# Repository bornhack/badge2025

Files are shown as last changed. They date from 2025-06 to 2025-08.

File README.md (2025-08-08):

# BornHack 2025 Circle Badge with LoRa

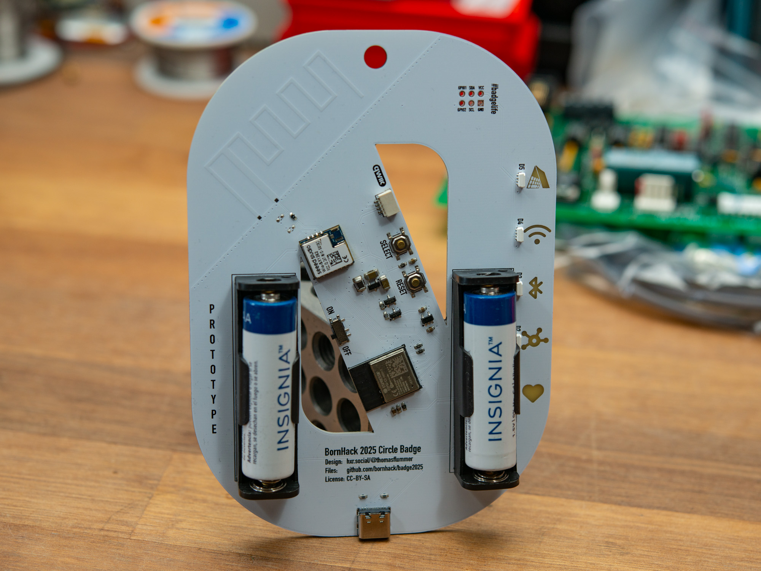
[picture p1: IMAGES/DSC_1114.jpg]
BornHack 2025 Circle Badge with LoRa (prototype)


This badge focuses on LoRa and wireless communication in general, as there are also WiFi and Bluetooth Low Energy included in the ESP32-C3 module.

It's a relatively bare bone design, with pretty much just the minimum elements to run a Meshtastic node or similar device.

Even though there is an antenna on the PCB for LoRa (868MHz) it's unfortunately not connected as the [LoRa module](https://www.seeedstudio.com/Wio-SX1262-Wireless-Module-p-5981.html) is the variant that has a connector (uf.L/IPEX), so an [external antenna](https://www.molex.com/en-us/products/part-detail/2111400100) is provided in the kit, that is designed to match with the connector on the module. The external antenna has selfadhesive backing, but don't mount it to the PCB, as most of the PCB is covered with copper, which will heavily decrese the performance, so if you want to stick it to something, better use a plastic case or similar.

The badge comes preinstalled with [Meshtastic](https://meshtastic.org/) firmware, that you can hook up to and configure using the Mestastic app on your phone (Android or iOS). The two apps are slightly different, but does have more or less the same overall features.

If you want to use Meshtastic for a longer period, it's recommended to power the badge via USB-C (simple  5V, eg. power bank or power adapter).

In addition to the LoRa module, there are 5 RGB LEDs on the side, a qwiic/StemmaQT connector and a footprint for a SAO v1.69bis connector for expansions, mostly for alternative firmwares.

## 3D Printable case

In the ```case``` folder is a desing, done in OpenSCAD, for a half or back case, that snaps on to the PCB and covers the back part with the battery holders, antenna and LEDs.

There are two versions, one fully closed, and one with a cutout for mounting it on a wall using a screw.

Both should print on most FDM printers without the need for support, with the back side facing down on the build plate.

## Projects running on the badge

Feel free to submit a PR adding on to this list with your project that runs on the badge.

- [Initial Meshtastic firmware](https://github.com/badgeteam/bornhack2025-meshtastic) ([Flasher tool](https://github.com/badgeteam/bornhack2025-flasher))
- _project name and link to more info_

## Designed in KiCad v9

To open the project, you will need to install a recent release version or one of the nightly builds, KiCad v8 or earlier won't open this design. The [schematic as a PDF](https://github.com/bornhack/badge2025/raw/main/schematics.pdf) is included for reference.

## License

The hardware design of the `main` branch of this repository is released under the following license:

* the "Creative Commons Attribution-ShareAlike 4.0 International License"
  (CC BY-SA 4.0) full text of this license is included in the LICENSE file
  and a copy can also be found at
  [http://creativecommons.org/licenses/by-sa/4.0/](http://creativecommons.org/licenses/by-sa/4.0/)

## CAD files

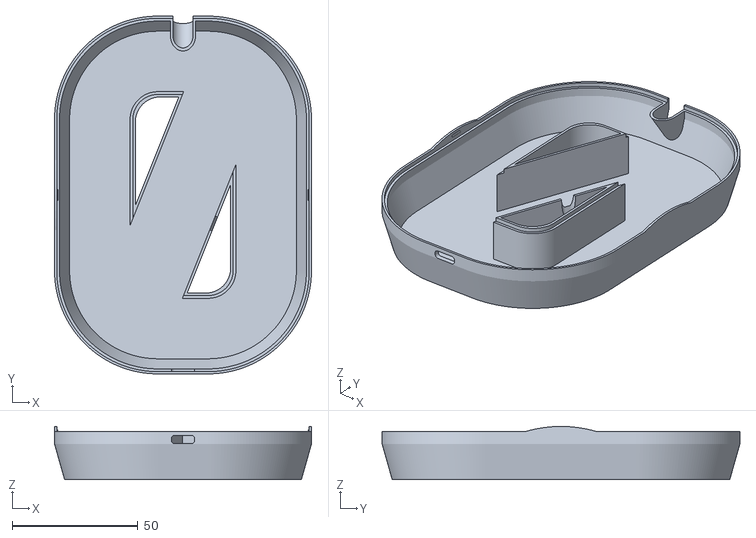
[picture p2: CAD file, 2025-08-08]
case/circle_badge_back_case.stl
102.0 x 142.0 x 21.1

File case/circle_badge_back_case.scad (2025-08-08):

/*
 * Case for BornHack 2025 badge
 *
 * Design: hxr.social/@thomasflummer
 *
 * License: CC-BY-SA
 *
 */

module half_rounded_cube(x, y, z, radius)
{
	hull()
	{
		for(xp = [-1, 1])
		{
			for(yp = [-1, 1])
			{
				for(zp = [-1, 1])
				{
					translate([xp*(x/2-radius), yp*(y/2-radius), zp*(z/2-0.1/2)])
						cylinder(r = radius, h = 0.1, center = true, $fn = 200);
				}
			}
		}
	}
}

module case()
{
	difference()
	{
		union()
		{
			hull()
			{
				translate([0, 0, -5/2+1.6])
					half_rounded_cube(100+2, 140+2, 5, 40+1);

				translate([0, 0, -16])
					half_rounded_cube(100-6, 140-6, 3, 40-3);
			}
			
			// extra sides for holding notches
			intersection()
			{
				translate([0, 0, 1.6])
					half_rounded_cube(100+2, 140+2, 10, 40+1);

				union()
				{
					for(xp = [-1, 1])
					{
						translate([xp*(100/2+0.1+1/2), 0, -100/2+1.6+2])
						rotate(90, [0, 1, 0])
							cylinder(d = 100, h = 1, center = true, $fn = 100);
					}
				}
			}
		}
		union()
		{
			// PCB cutout
			difference()
			{
				translate([0, 0, 1.6/2])
					half_rounded_cube(100+.2, 140+.2, 1.61, 40+0.1);

				difference()
				{
					translate([0, 0, 0])
						half_rounded_cube(40-.2, 80-.2, 40, 10-0.1);
						
					translate([0, 0, 0])
					rotate(-atan(20/50), [0, 0, 1])
						cube([29.8 + 0.2, 100, 40.1], center = true);
				}
			}

			// main opening
			difference()
			{
				hull()
				{
					translate([0, 0, -5/2+1.6])
						half_rounded_cube(100-2, 140-2, 5, 40-1);

					translate([0, 0, -16+1.5])
						half_rounded_cube(100-6-4, 140-6-4, 3, 40-3-2);
				}

				difference()
				{
					translate([0, 0, 0])
						half_rounded_cube(40+2, 80+2, 40, 10+1);
						
					translate([0, 0, 0])
					rotate(-atan(20/50), [0, 0, 1])
						cube([29.8+0.2, 100, 40.1], center = true);
				}
				
				// lanyard opening sides
				hull()
				{
					translate([0, 140/2, -5/2+1.6])
					rotate(35, [1, 0, 0])
						half_rounded_cube(10, 20, 30, 5);
					
				}
			}

			// lanyard cutout
			hull()
			{
				translate([0, 140/2, -5/2+1.6])
				rotate(35, [1, 0, 0])
					half_rounded_cube(8, 18, 30, 4);
				
			}

			// inner openings
			difference()
			{
				translate([0, 0, 0])
					half_rounded_cube(40-.2-2, 80-.2-2, 40, 10-0.1);
					
				translate([0, 0, 0])
				rotate(-atan(20/50), [0, 0, 1])
					cube([29.8 + 0.2 + 2, 100, 40.1], center = true);
			}
			
			// power switch
			translate([0, 0, 0])
			rotate(-atan(20/50), [0, 0, 1])
			translate([29.8/2+1.5, -6, 0])
			rotate(-15, [0, 1, 0])
				half_rounded_cube(4, 6, 12, 2);

			// USB-C cutout
			translate([0, -140/2, -3.2/2])
			rotate(90, [1, 0, 0])
				half_rounded_cube(9.2, 3.2, 20, 1.2);

			hull()
			{
				translate([0, -140/2+10/2, -3.2/2])
				rotate(90, [1, 0, 0])
					half_rounded_cube(9.2, 3.2, 10, 1.2);

				translate([0, -140/2+10/2, -3.2/2+3])
				rotate(90, [1, 0, 0])
					half_rounded_cube(9.2, 3.2, 10, 1.2);
			}

			// wall mounting hole
			translate([0, 140/2-20, -16])
				cylinder(d = 10, h = 10, center = true, $fn = 100);

			translate([0, 140/2-20, -16])
			hull()
			{
				cylinder(d = 4.5, h = 10, center = true, $fn = 100);

				translate([0, 8, 0])
					cylinder(d = 4.5, h = 10, center = true, $fn = 100);
			}
		}
	}
	
	// holding nothches
	union()
	{
		for(xp = [-1, 1])
		{
			translate([xp*(100/2+0.2), 0, 1.6+0.4])
			hull()
			{
				for(yp = [-1, 1])
				{
					translate([0, yp*2, 0])
						#sphere(d = 1, $fn = 50);
				}
			}
		}
	}

}

difference()
{
	union()
	{
		color("#ffafc7")
		case();

		if(true)
		{
			//color("#ffffff")
			translate([-100/2, 140/2, 0])
				%import("circle-badge.stl");
		}
	}
	union()
	{
		if(false)
		{
			rotate(55, [0, 0, 1])
			translate([0, -100, 0])
				cube([200, 200, 200], center = true);
		}
	}
}

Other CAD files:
case/circle_badge_back_case_wall_mount.stl

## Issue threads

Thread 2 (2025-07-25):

Documentation missing

MikeTango, 2025-07-25:
Moin,

here is what i found out in the first 5 Minutes:

1) The device doesn't come with a region setting so it's on the wrong channels

2) The device shows 5 red LEDs if the batteries are empty

3) The device doesn't seem to have a charging circuit for the batteries

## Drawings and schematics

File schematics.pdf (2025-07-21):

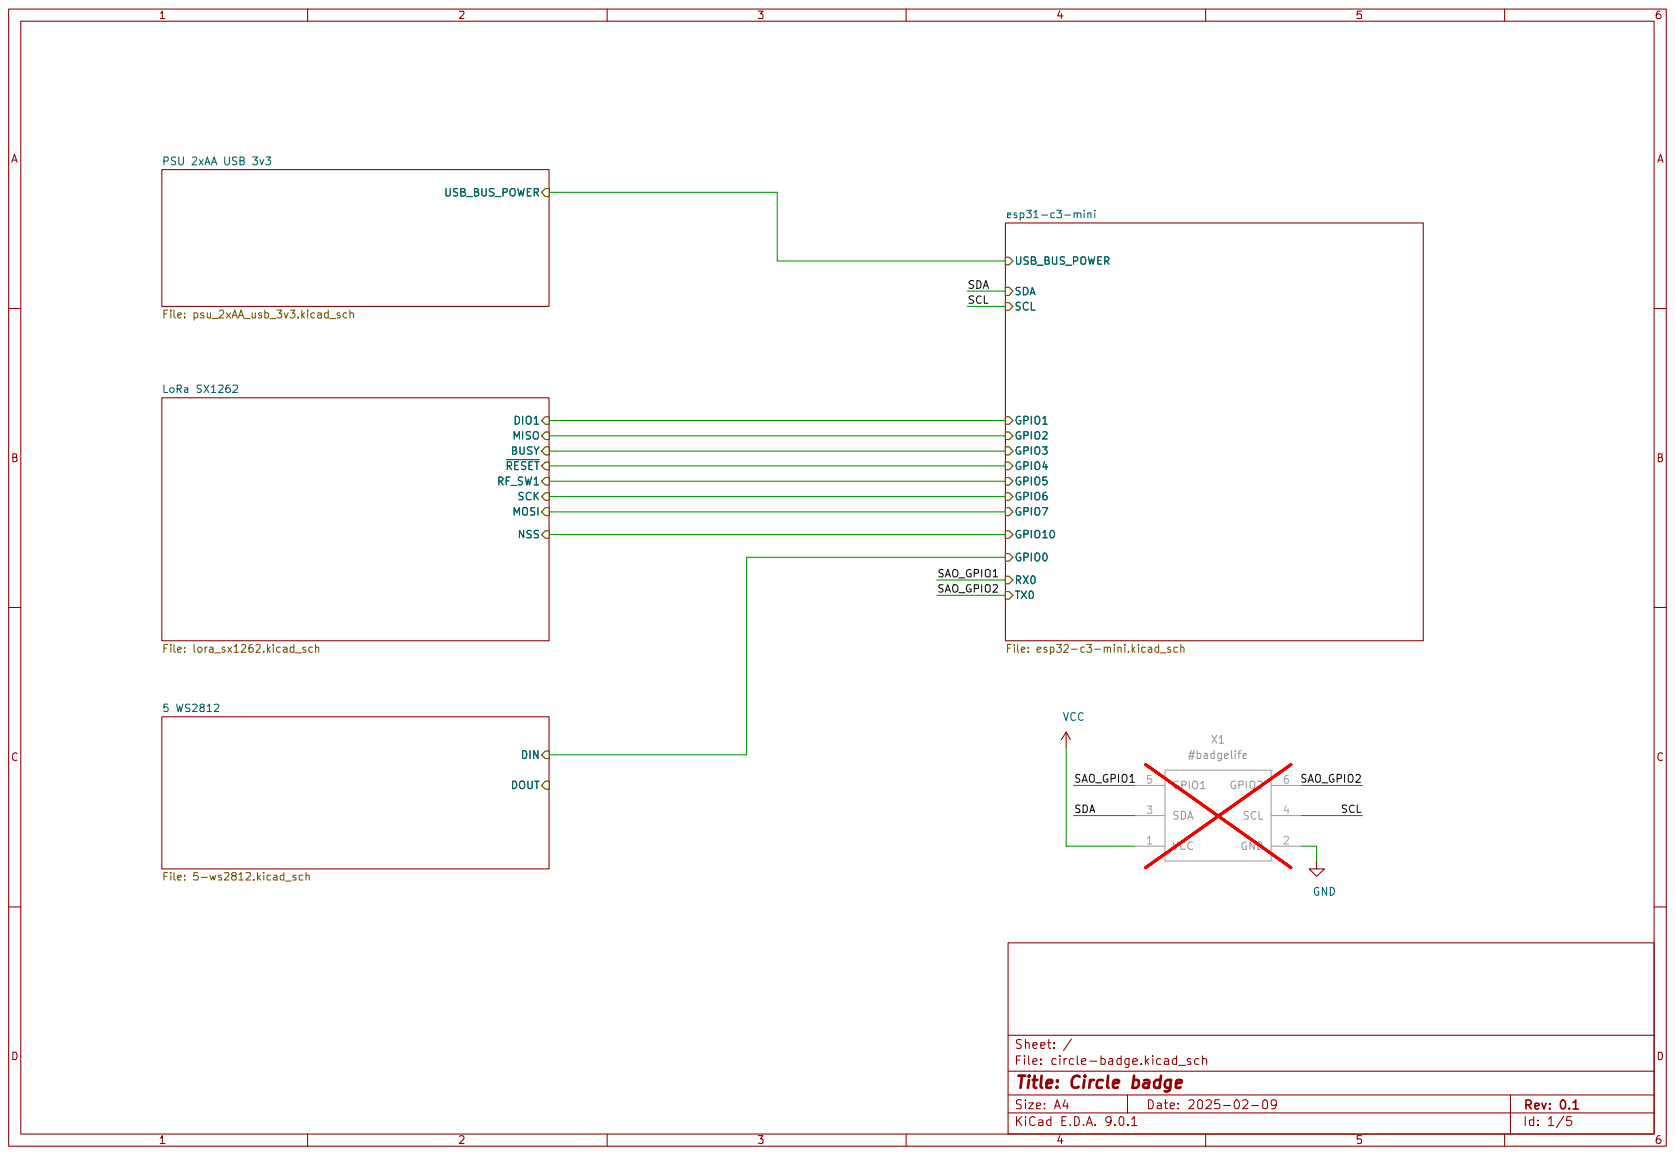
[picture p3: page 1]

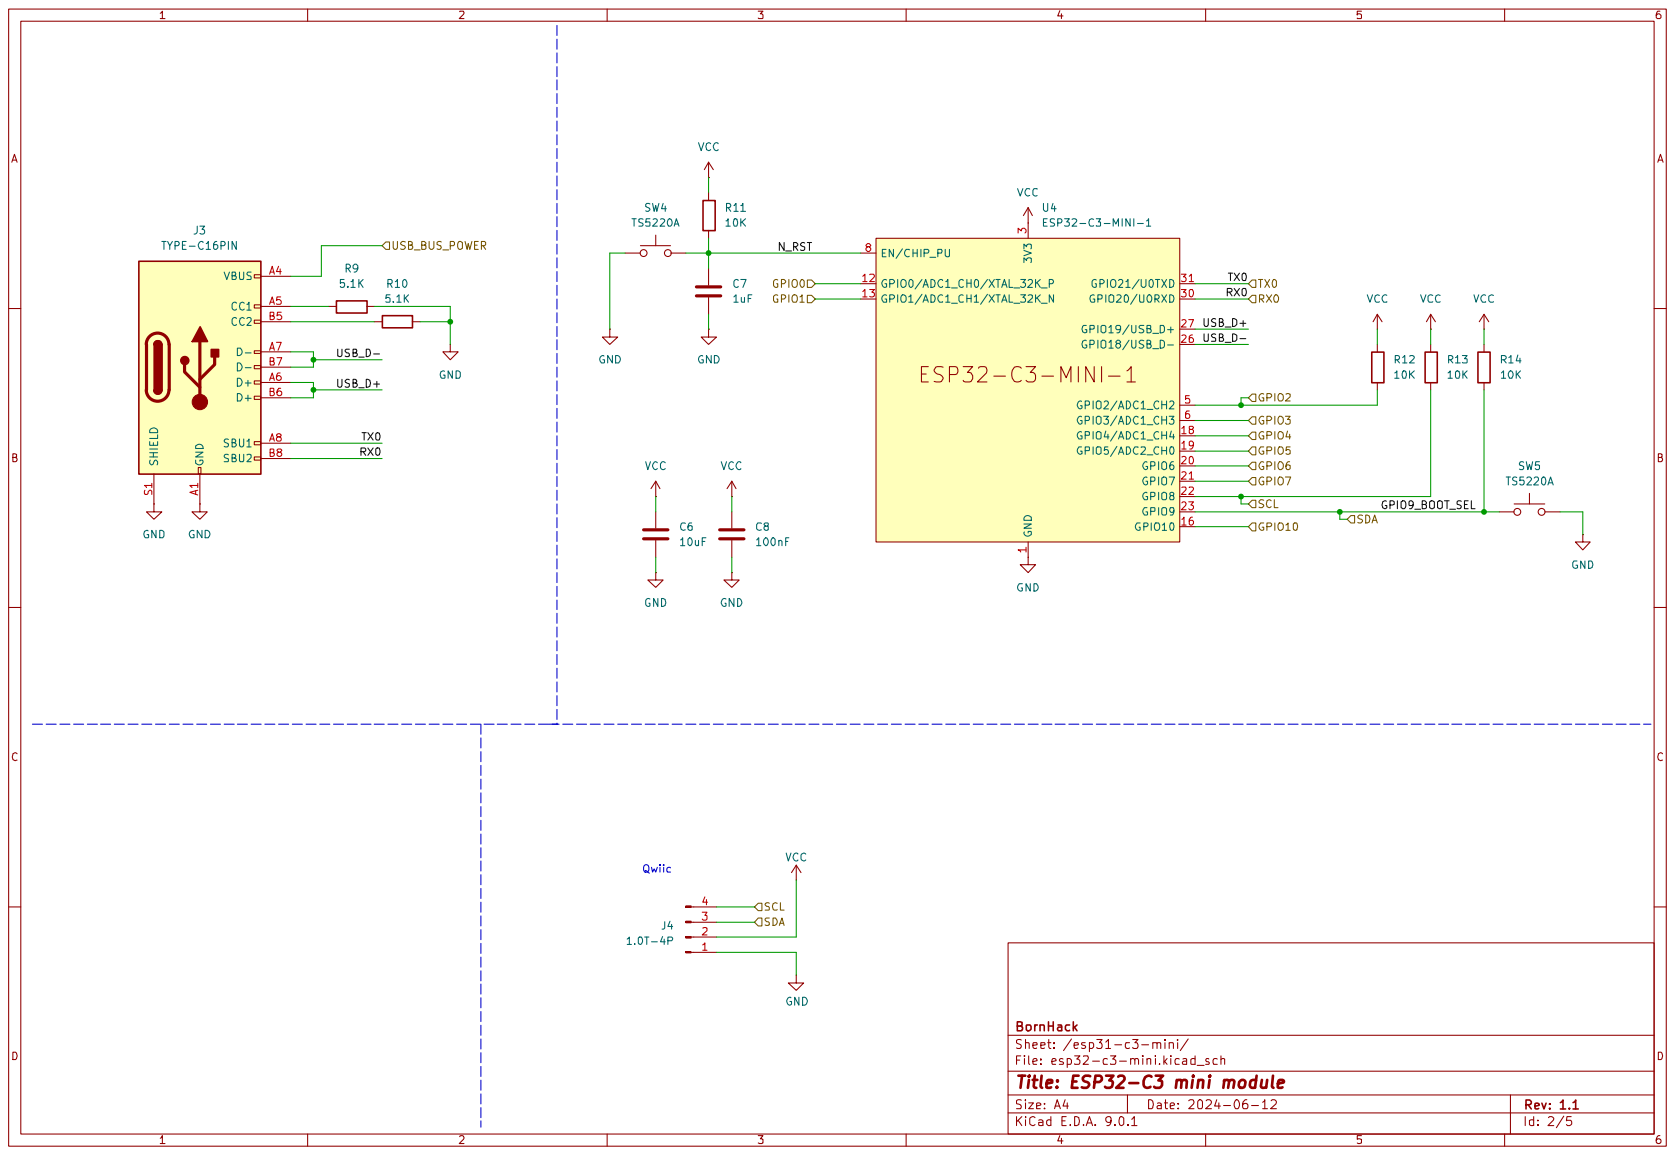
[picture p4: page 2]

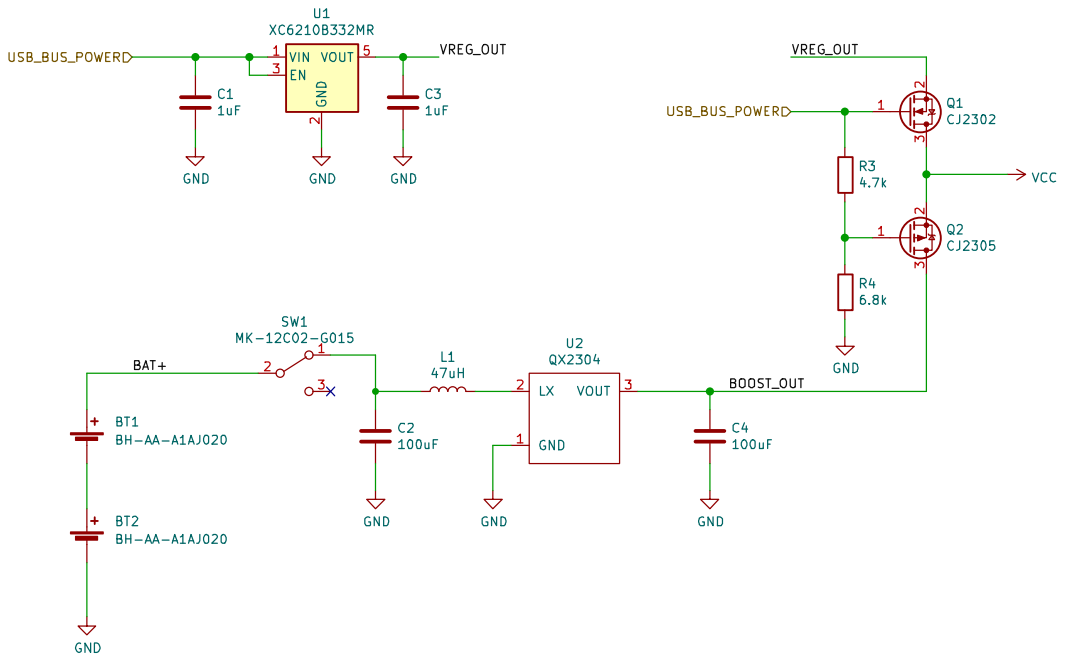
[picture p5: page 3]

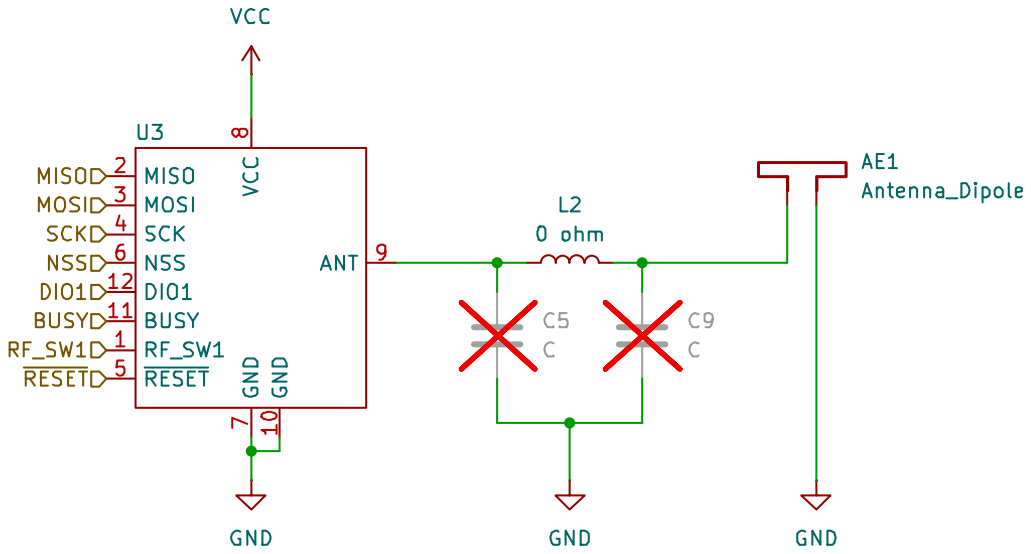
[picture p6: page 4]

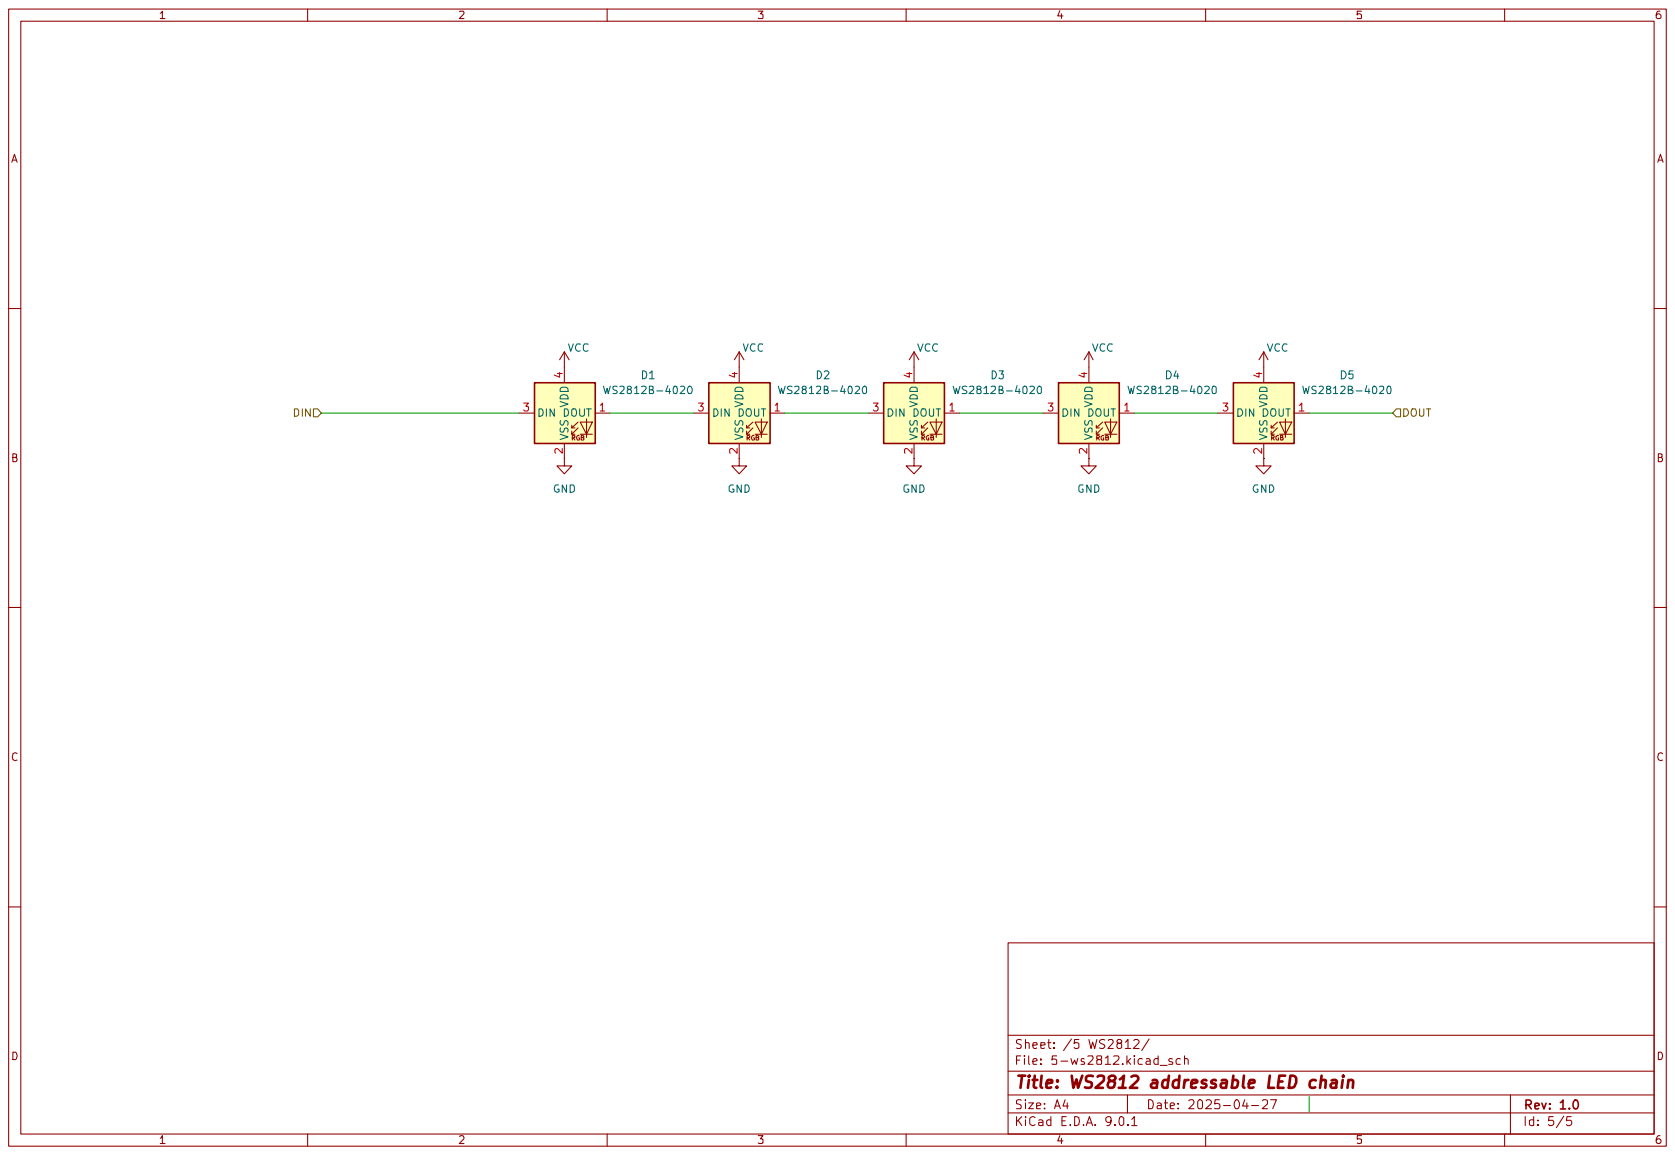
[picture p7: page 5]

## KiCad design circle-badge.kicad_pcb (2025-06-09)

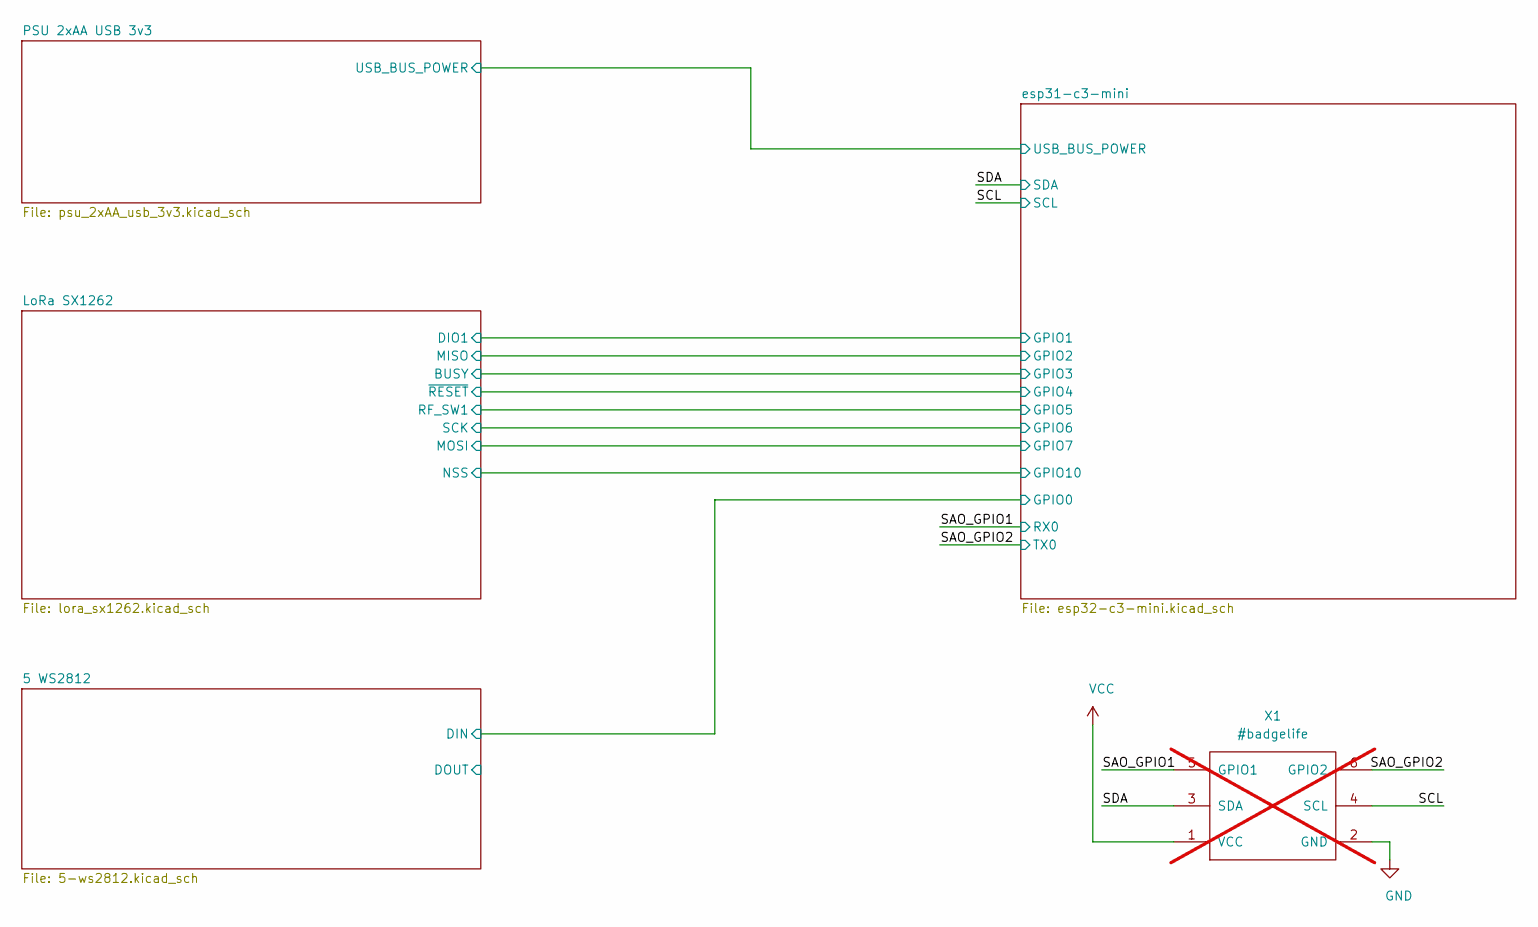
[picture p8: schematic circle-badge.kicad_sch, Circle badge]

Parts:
X1: #badgelife; Badgelife-SAOv169-BADGE-2x3; not fitted

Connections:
/SAO_GPIO1: X1.5 (GPIO1); also elsewhere on the board
/SAO_GPIO2: X1.6 (GPIO2); also elsewhere on the board
/SCL: X1.4 (SCL); also elsewhere on the board
/SDA: X1.3 (SDA); also elsewhere on the board
GND: X1.2 (GND); also elsewhere on the board
VCC: X1.1 (VCC); also elsewhere on the board

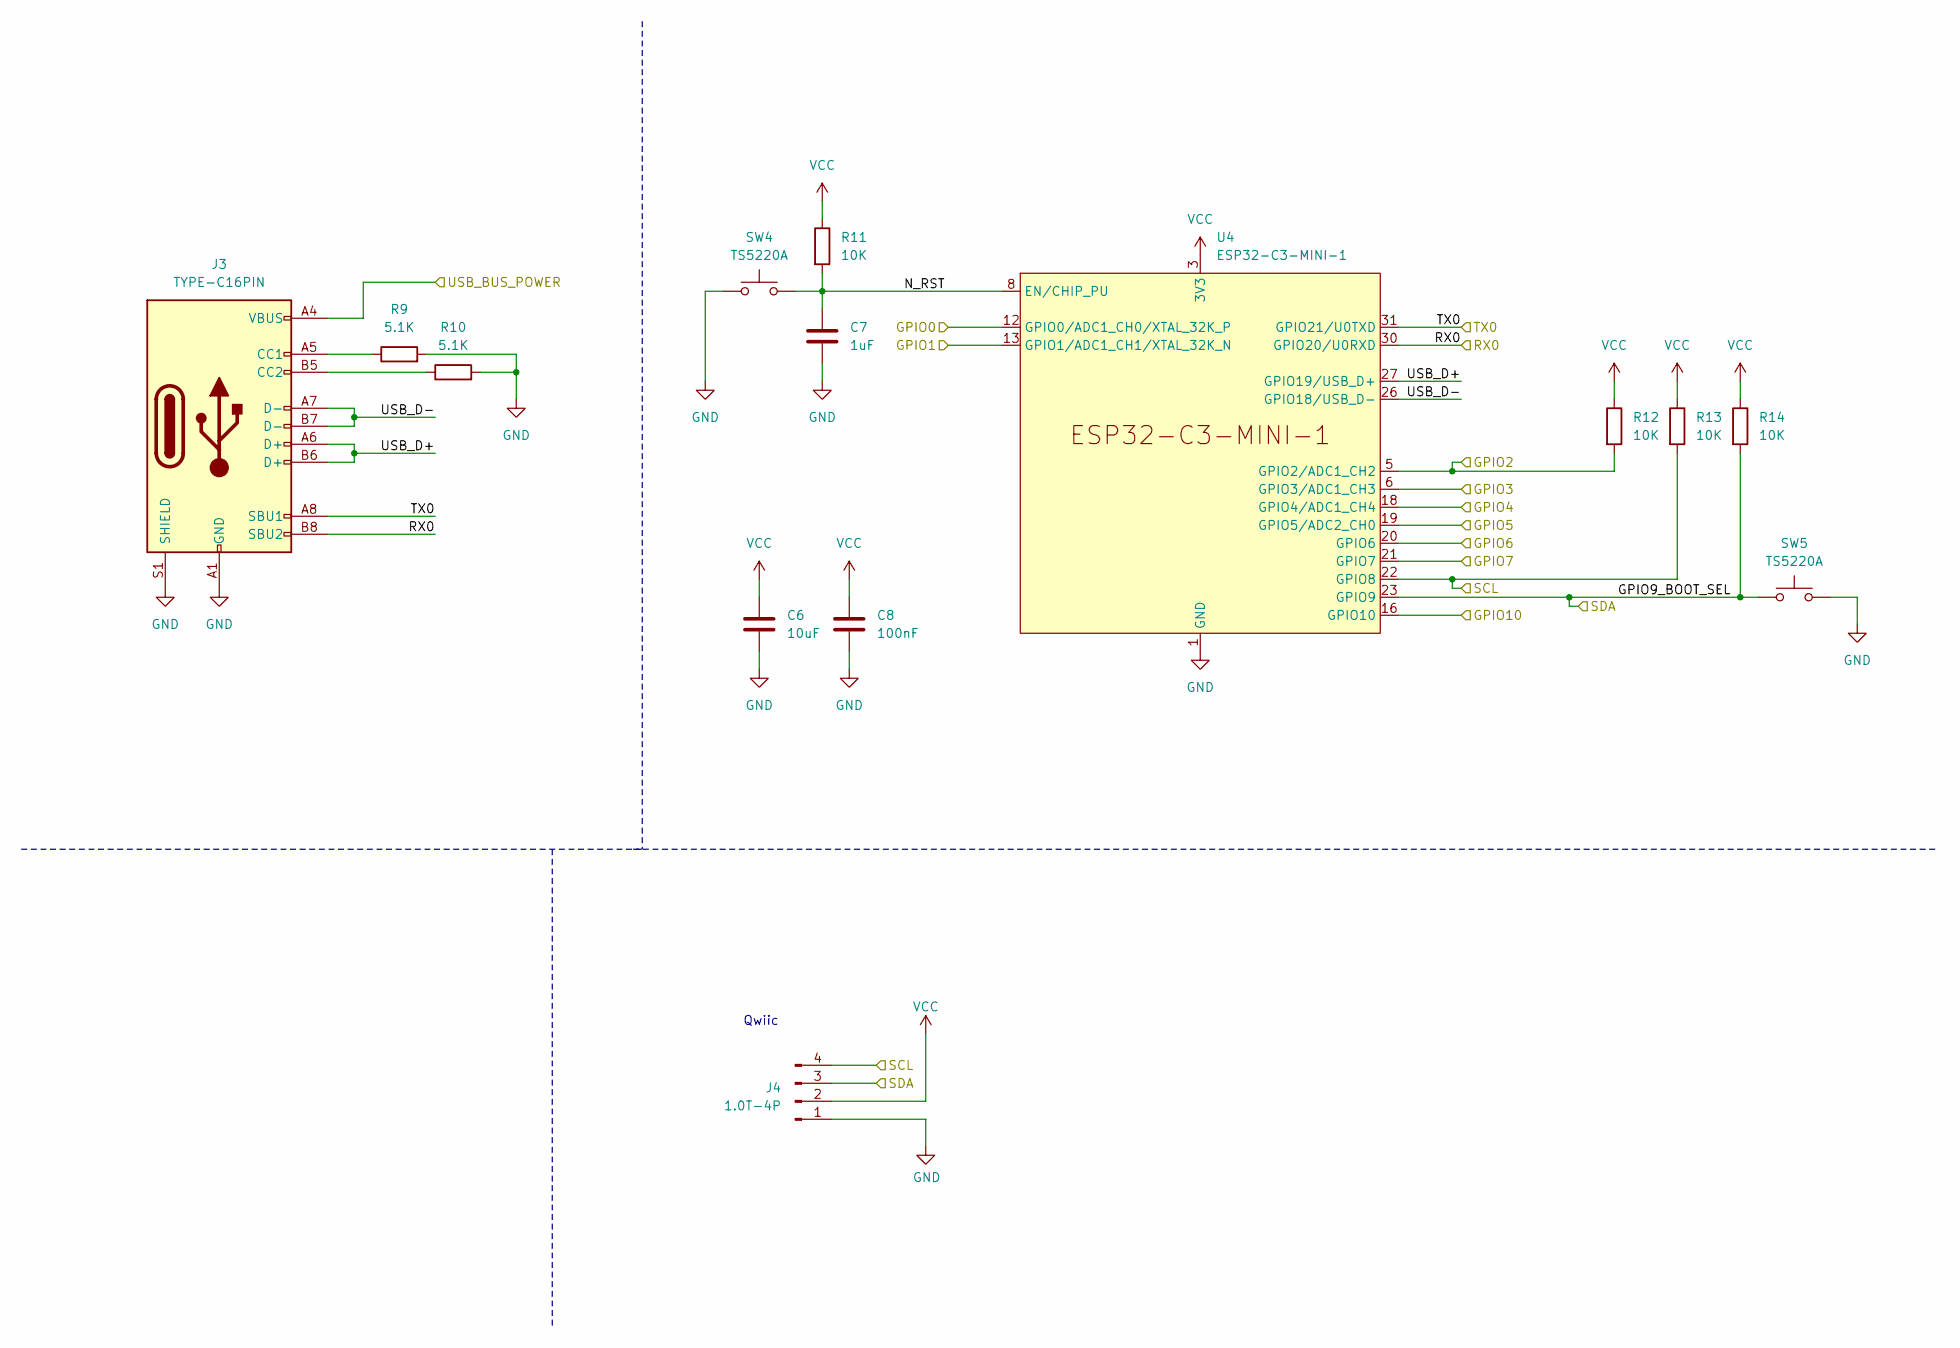
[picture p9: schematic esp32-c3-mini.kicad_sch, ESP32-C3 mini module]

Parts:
C6: 10uF; C_0603_1608Metric
C7: 1uF; C_0603_1608Metric
C8: 100nF; C_0603_1608Metric
J3: TYPE-C16PIN; USB_C_Receptacle_XKB_U262-16XN-4BVC11; LCSC C393939
J4: 1.0T-4P; JST_SH_SM04B-SRSS-TB_1x04-1MP_P1.00mm_Horizontal; LCSC C145956
R9, R10: 5.1K; R_0603_1608Metric
R11, R12, R13, R14: 10K; R_0603_1608Metric
SW4, SW5: TS5220A; SW_SPST_TL3342; LCSC C412370
U4: ESP32-C3-MINI-1

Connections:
/5 WS2812/DIN: U4.12 (GPIO0/ADC1_CH0/XTAL_32K_P); also elsewhere on the board
/LoRa SX1262/BUSY: U4.6 (GPIO3/ADC1_CH3); also elsewhere on the board
/LoRa SX1262/DIO1: U4.13 (GPIO1/ADC1_CH1/XTAL_32K_N); also elsewhere on the board
/LoRa SX1262/MISO: R12.2, U4.5 (GPIO2/ADC1_CH2); also elsewhere on the board
/LoRa SX1262/MOSI: U4.21 (GPIO7); also elsewhere on the board
/LoRa SX1262/NSS: U4.16 (GPIO10); also elsewhere on the board
/LoRa SX1262/RF_SW1: U4.19 (GPIO5/ADC2_CH0); also elsewhere on the board
/LoRa SX1262/SCK: U4.20 (GPIO6); also elsewhere on the board
/LoRa SX1262/~RESET: U4.18 (GPIO4/ADC1_CH4); also elsewhere on the board
/PSU 2xAA USB 3v3/USB_BUS_POWER: J3.A4 (VBUS), J3.A9 (VBUS), J3.B4 (VBUS), J3.B9 (VBUS); also elsewhere on the board
/SAO_GPIO1: J3.B8 (SBU2), U4.30 (GPIO20/U0RXD); also elsewhere on the board
/SAO_GPIO2: J3.A8 (SBU1), U4.31 (GPIO21/U0TXD); also elsewhere on the board
/SCL: J4.4, R13.2, U4.22 (GPIO8); also elsewhere on the board
/SDA: J4.3, R14.2, SW5.1, U4.23 (GPIO9); also elsewhere on the board
/esp31-c3-mini/N_RST: C7.1, R11.2, SW4.2, U4.8 (EN/CHIP_PU)
/esp31-c3-mini/USB_D+: J3.A6 (D+), J3.B6 (D+), U4.27 (GPIO19/USB_D+)
/esp31-c3-mini/USB_D-: J3.A7 (D-), J3.B7 (D-), U4.26 (GPIO18/USB_D-)
GND: C6.2, C7.2, C8.2, J3.A1 (GND), J3.A12 (GND), J3.B1 (GND), J3.B12 (GND), J3.S1 (SHIELD), J4.1, R9.2, R10.2, SW4.1, SW5.2, U4.1 (GND), U4.2 (GND), U4.11 (GND), U4.14 (GND), U4.36 (GND), U4.37 (GND), U4.38 (GND), U4.39 (GND), U4.40 (GND), U4.41 (GND), U4.42 (GND), U4.43 (GND), U4.44 (GND), U4.45 (GND), U4.46 (GND), U4.47 (GND), U4.48 (GND), U4.49 (GND), U4.50 (GND), U4.51 (GND), U4.52 (GND), U4.53 (GND); also elsewhere on the board
unnamed: J3.A5 (CC1), R9.1
unnamed: J3.B5 (CC2), R10.1
VCC: C6.1, C8.1, J4.2, R11.1, R12.1, R13.1, R14.1, U4.3 (3V3); also elsewhere on the board

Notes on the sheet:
Qwiic

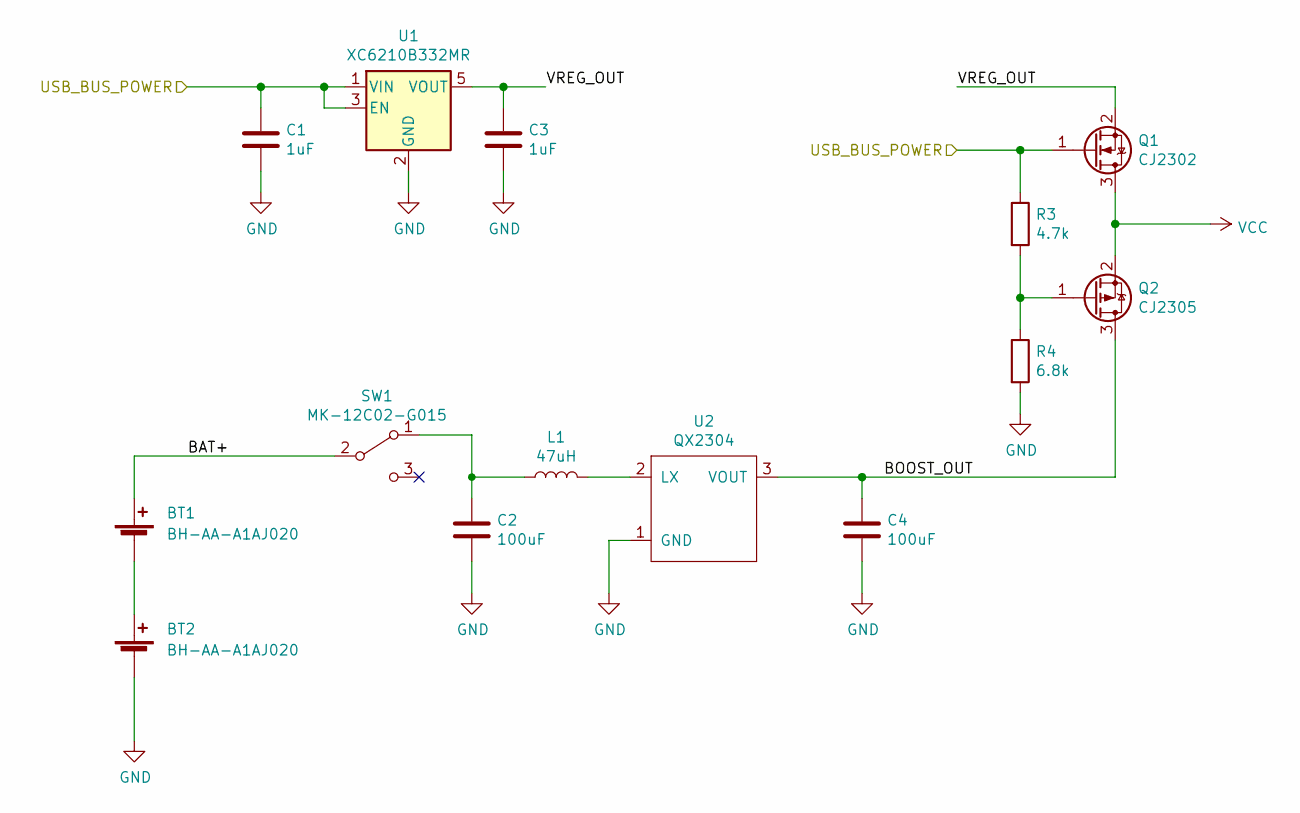
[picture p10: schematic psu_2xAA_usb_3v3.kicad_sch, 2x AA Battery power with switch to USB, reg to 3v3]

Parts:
BT1, BT2: BH-AA-A1AJ020; Single_AA; LCSC C5290181
C1, C3: 1uF; C_0603_1608Metric
C2, C4: 100uF; C_1206_3216Metric
L1: 47uH; L_1210_3225Metric
Q1: CJ2302; SOT-23; LCSC C8548
Q2: CJ2305; SOT-23; LCSC C8549
R3: 4.7k; R_0603_1608Metric
R4: 6.8k; R_0603_1608Metric
SW1: MK-12C02-G015; SW_SPDT_PCM12; LCSC C2911519
U1: XC6210B332MR; SOT-23-5; LCSC C3021084
U2: QX2304; SOT-23; LCSC C219038

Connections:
/PSU 2xAA USB 3v3/BAT+: BT1.1 (+), SW1.2 (B)
/PSU 2xAA USB 3v3/BOOST_OUT: C4.1, Q2.3 (D), U2.3 (VOUT)
/PSU 2xAA USB 3v3/USB_BUS_POWER: C1.1, Q1.1 (G), R3.1, U1.1 (VIN), U1.3 (EN); also elsewhere on the board
/PSU 2xAA USB 3v3/VREG_OUT: C3.1, Q1.2 (S), U1.5 (VOUT)
GND: BT2.2 (-), C1.2, C2.2, C3.2, C4.2, R4.2, U1.2 (GND), U2.1 (GND); also elsewhere on the board
unnamed: BT1.2 (-), BT2.1 (+)
unnamed: Q2.1 (G), R3.2, R4.1
unnamed: C2.1, L1.1, SW1.1 (A)
unnamed: L1.2, U2.2 (LX)
VCC: Q1.3 (D), Q2.2 (S); also elsewhere on the board

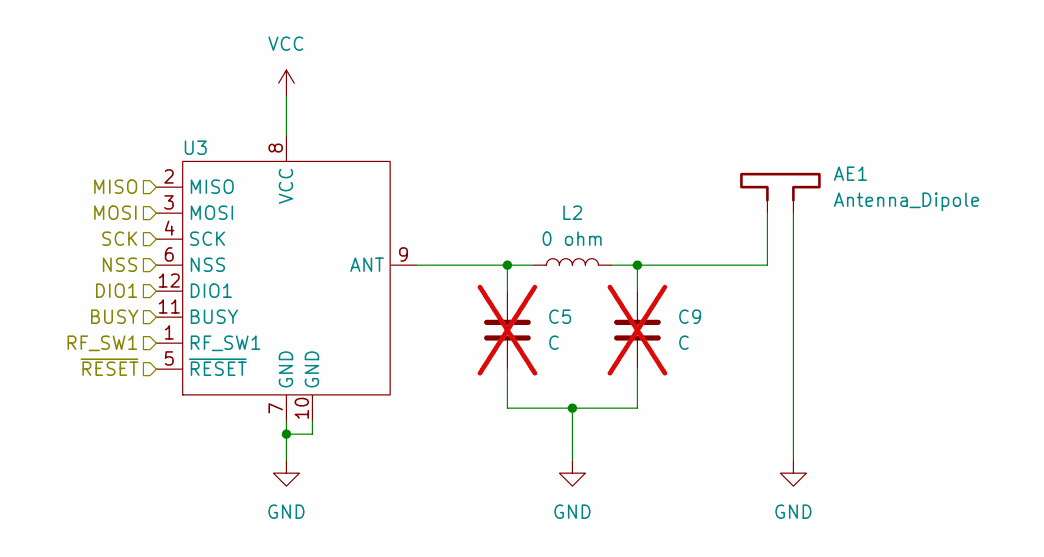
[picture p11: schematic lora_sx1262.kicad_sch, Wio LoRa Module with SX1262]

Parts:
AE1: Antenna_Dipole; 868 Inverted F Antenna
C5, C9: C; C_0603_1608Metric; not fitted
L2: 0 ohm; L_0603_1608Metric
U3: Wio-SX1262 / 113991436; MODULE12P-1.27-11X11.6MM

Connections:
/LoRa SX1262/BUSY: U3.11 (BUSY); also elsewhere on the board
/LoRa SX1262/DIO1: U3.12 (DIO1); also elsewhere on the board
/LoRa SX1262/MISO: U3.2 (MISO); also elsewhere on the board
/LoRa SX1262/MOSI: U3.3 (MOSI); also elsewhere on the board
/LoRa SX1262/NSS: U3.6 (NSS); also elsewhere on the board
/LoRa SX1262/RF_SW1: U3.1 (RF_SW1); also elsewhere on the board
/LoRa SX1262/SCK: U3.4 (SCK); also elsewhere on the board
/LoRa SX1262/~RESET: U3.5 (~RESET); also elsewhere on the board
GND: AE1.2, C5.2, C9.2, U3.7 (GND), U3.10 (GND); also elsewhere on the board
unnamed: AE1.1, C9.1, L2.2
unnamed: C5.1, L2.1, U3.9 (ANT)
VCC: U3.8 (VCC); also elsewhere on the board

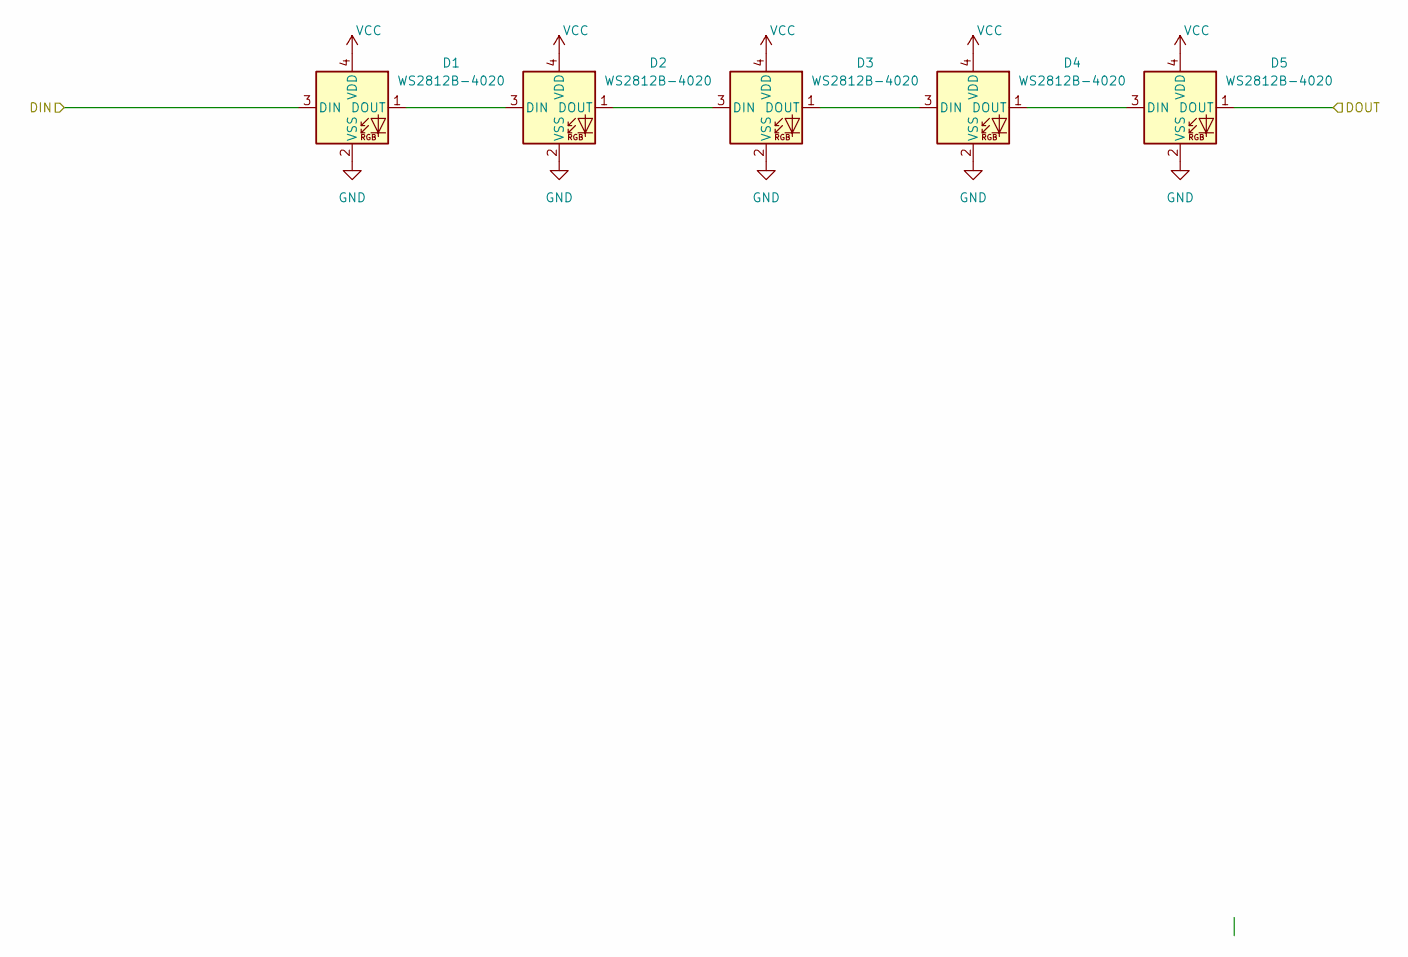
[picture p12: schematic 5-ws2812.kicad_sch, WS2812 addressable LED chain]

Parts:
D1, D2, D3, D4, D5: WS2812B-4020; LCSC C965557

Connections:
/5 WS2812/DIN: D1.3 (DIN); also elsewhere on the board
/5 WS2812/DOUT: D5.1 (DOUT)
GND: D1.2 (VSS), D2.2 (VSS), D3.2 (VSS), D4.2 (VSS), D5.2 (VSS); also elsewhere on the board
unnamed: D1.1 (DOUT), D2.3 (DIN)
unnamed: D2.1 (DOUT), D3.3 (DIN)
unnamed: D3.1 (DOUT), D4.3 (DIN)
unnamed: D4.1 (DOUT), D5.3 (DIN)
VCC: D1.4 (VDD), D2.4 (VDD), D3.4 (VDD), D4.4 (VDD), D5.4 (VDD); also elsewhere on the board

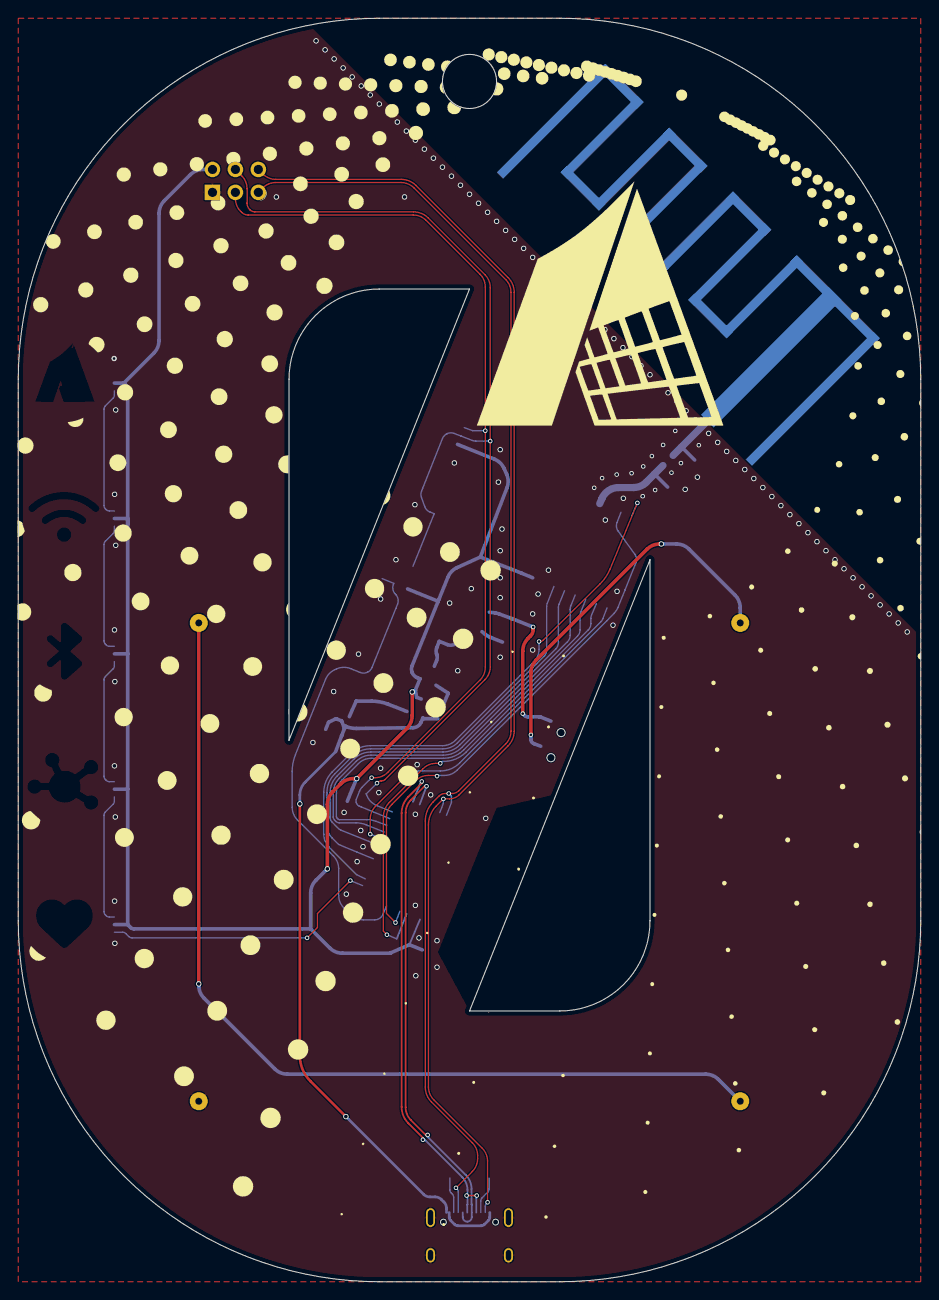
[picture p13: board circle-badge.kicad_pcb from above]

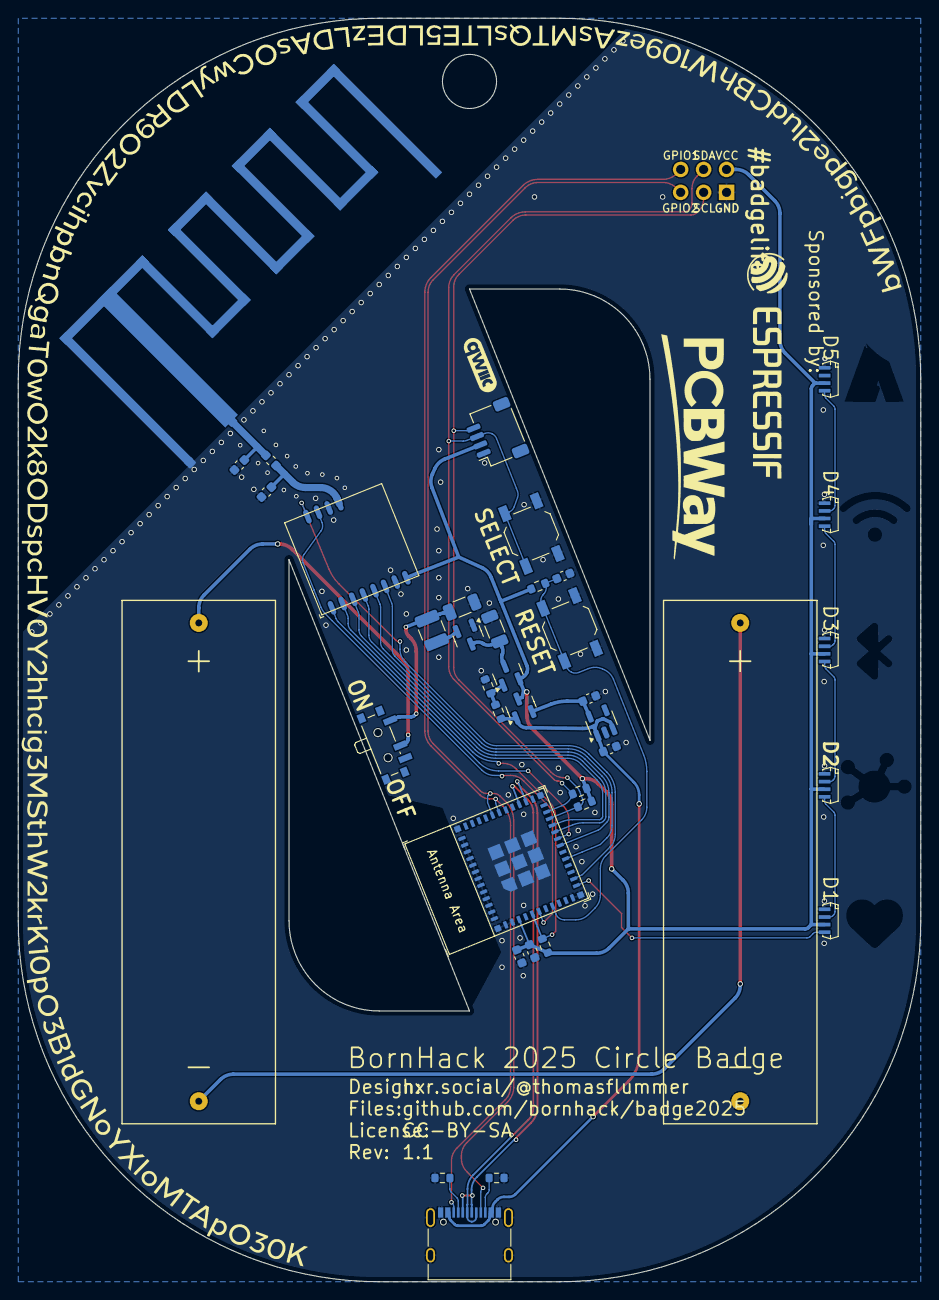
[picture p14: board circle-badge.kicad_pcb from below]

Board: 2 copper layers, 100.0 x 140.0 mm, 39 parts (38 on the bottom side), 34 nets.

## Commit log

2025-04-28 Initial version
    [5-ws2812.kicad_sch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]
2025-06-08 Added front artwork and token on the back
    Also:
    - Tweaked the trace to the antenna to hopefully better match 50ohm impedance
    - Tweaked all traces to use fillet on all corners
    - Added/fixed parts information
    [5-ws2812.kicad_sch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]
2025-06-09 Changed mask layer for USB-C connector
    Made sure mask bridges are 0.22mm wide
    [circle-badge-B_Cu.gbl, circle-badge-B_Mask.gbs, circle-badge-B_Paste.gbp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]
2025-08-08 Added case design
    [circle_badge_back_case.scad, circle_badge_back_case.stl, circle_badge_back_case_wall_mount.stl]
